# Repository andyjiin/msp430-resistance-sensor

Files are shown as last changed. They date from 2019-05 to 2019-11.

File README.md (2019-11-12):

# msp430-resistance-sensor
Resistance Sensor Embedded System built for ECE 298 by Andy Jin and Kelly Tang

### Problem Statement
Resistance can be measured a variety of different ways, but the setup is often tedious without the proper equipment and there is a lot of room for error. Design a resistance sensing device that utilizes analog voltage sensing and has notable features such as auto-ranging and user-friendly display to solve this problem 

### Design
Our design for the resistance sensor is bascially that of a simple voltage divider. Given a constant input voltage, and a known reference resistor, we can measure the voltage drop across the unknown resistance and solve for the unknown resistance. To give it the auto-ranging feature, we need a variety of reference resistors which will switch automatically based on input resistance. 

### Prototype
Shown below is the initial prototype working with a 8-to-1 mux breakout board and MSP430 discovery board.
<p align="center">
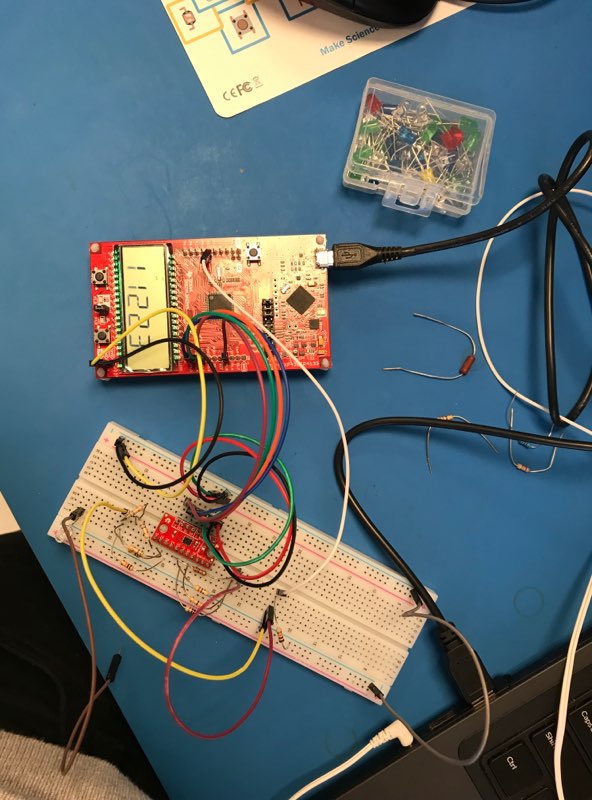
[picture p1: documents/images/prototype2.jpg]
  
</p>

### PCB
Once we finalized the design, a PCB was manufactured and we were able to stress test our product to ensure it met specifications and requirements. We can see in the image that given a 620 Ohm resistor, our output was 617 Ohm which gave us an error of < 1% which was well below our expected at ~5% (of course we have to note that the resistor itself has internal error). 
<p align="center">
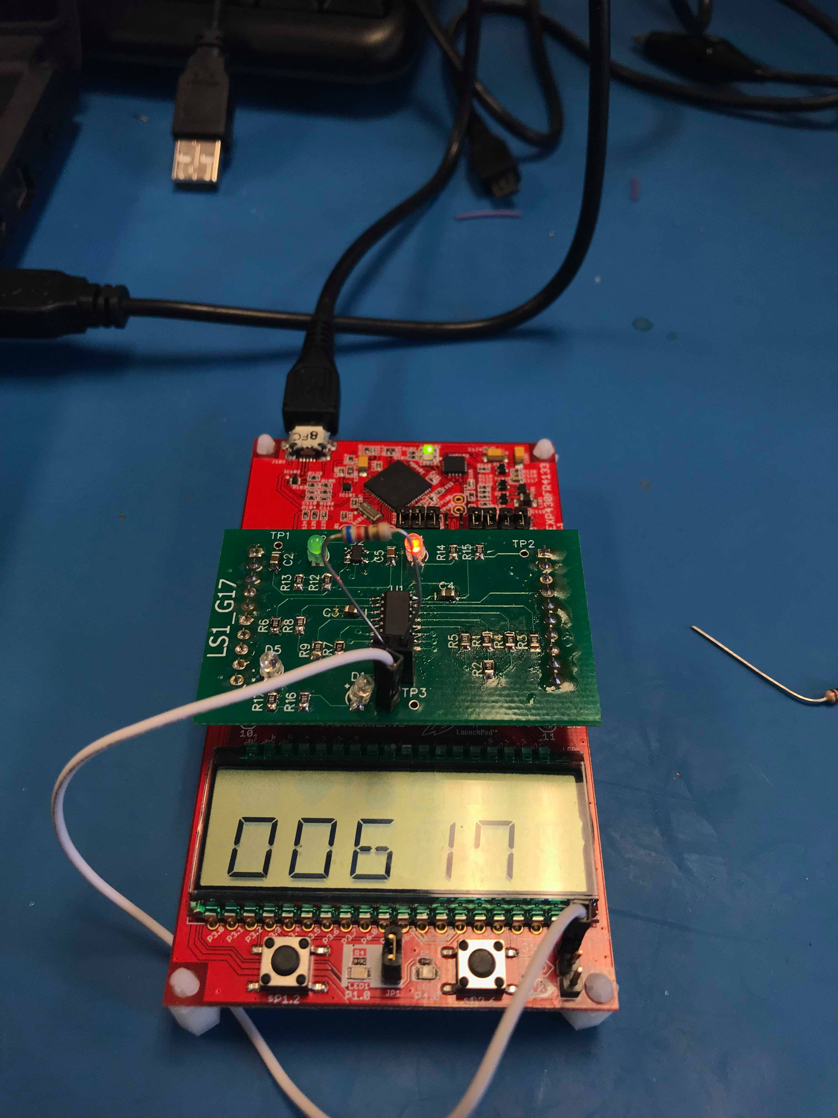
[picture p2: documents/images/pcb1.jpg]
  
</p>

### Remarks
We had some hardware issues that we would like to resolve if there were to be a rev 2. Firstly, we found our accuracy dropped considerable beyond 10 kOhm which is due to the fact that the low-impedence ADC input of the MSP430 adds another resistor in parallel with the input resistor which would skew the voltage reading across our unknown resistor. We would like to add some sort of buffer between the resistor circuit and the ADC input pin. Secondly, we had to manually short one of a pins which was misconnected (as seen in the images with the white jumper cable).

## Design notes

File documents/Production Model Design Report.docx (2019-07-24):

# Production Model Design Report

S2019

Lab Section: | 1 | Group: | 17

# Team Members

# | Name | Role

1 | Andy Jin | Software, prototyping and integration testing
2 | Kelly Tang | Schematic, layout and PCB bring-up

# Design Overview

## Problem Statement

Resistance can be measured a variety of different ways, but the setup is often tedious without the proper equipment and there is a lot of room for error. Design a resistance sensing device that utilizes analog voltage sensing and has notable features such as auto-ranging and user-friendly display to solve this problem.

## Design Scope

The project solves the problem by using a simple voltage divider in conjunction with the MSP430’s on-board ADC to measure voltage across the unknown resistance and compare the results with a known reference resistor. The reference resistor is selectable to give the device the auto-ranging functionality and the measured resistance is displayed to the user on the LCD display.

It was assumed that the device will operate in ideal weather conditions and the object to measure is of a reasonable size (i.e. it is able to fit between the resistance sensing nodes).

## Project Design Requirements

1. The system must be able to successfully determine the resistance of an unknown object within a 10% degree of precision and accuracy
2. The system must relay information in a clear and concise format to the user
3. The system must be able to automatically adjust its resistance range according to provided object
4. The latency between connecting probes to the object and the output of the information to the user must be less than 0.1s

## System-Level Design (High-Level)

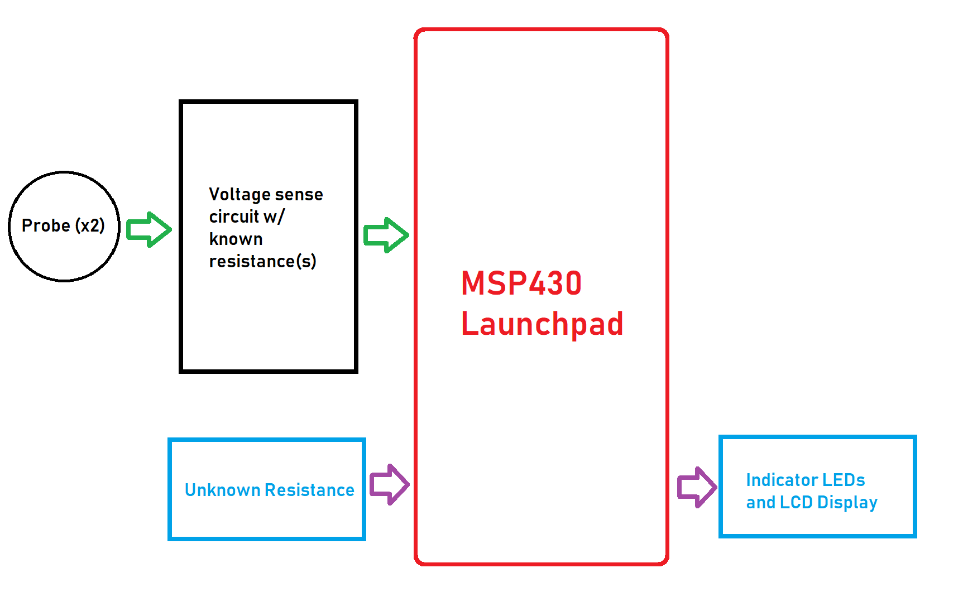
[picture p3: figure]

Figure 1: Updated Resistance Sensor High Level Block Diagram

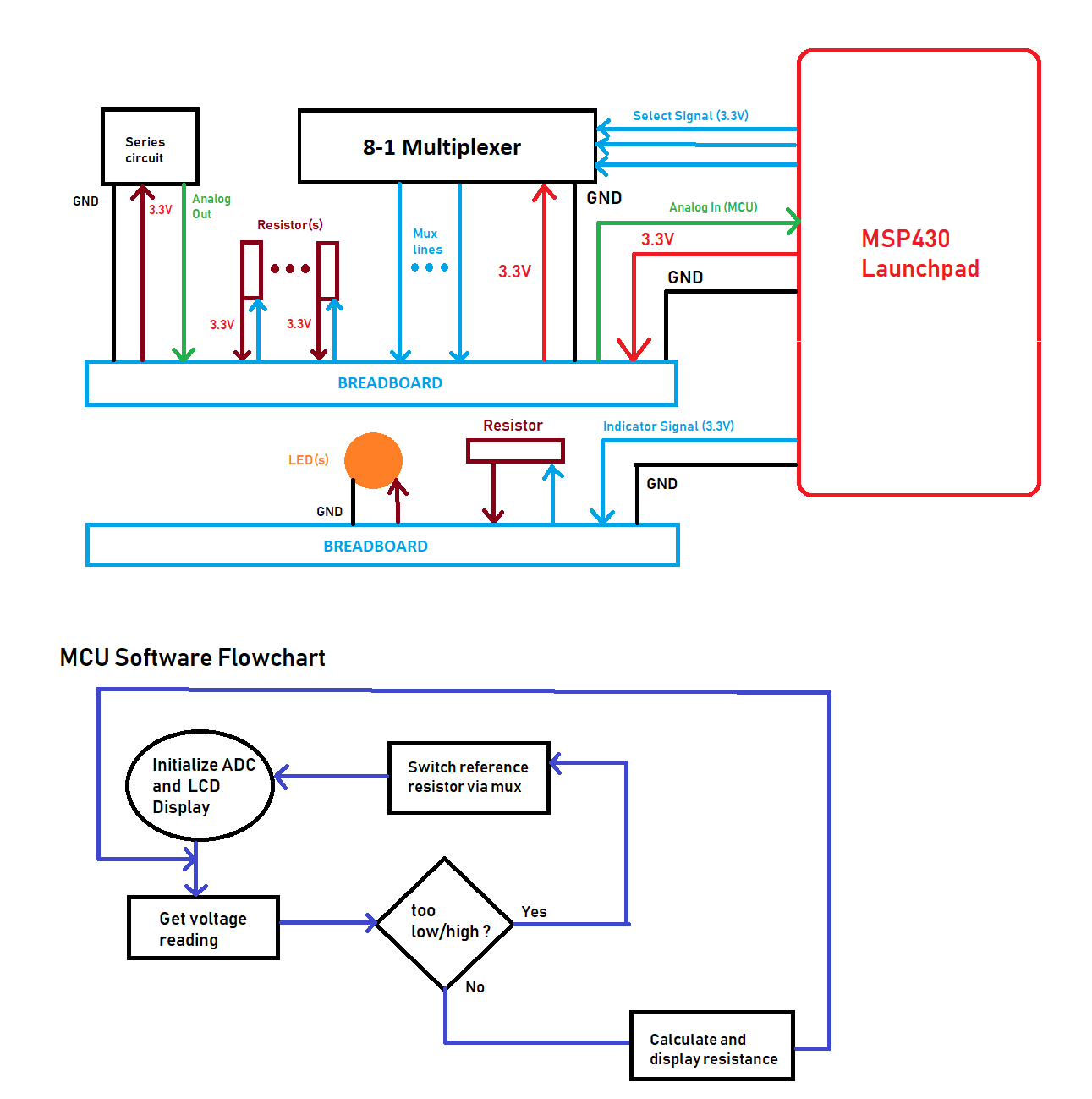
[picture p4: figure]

Figure 2: Updated Feasibility Model Design and a Software Flowchart

## Completed Prototype

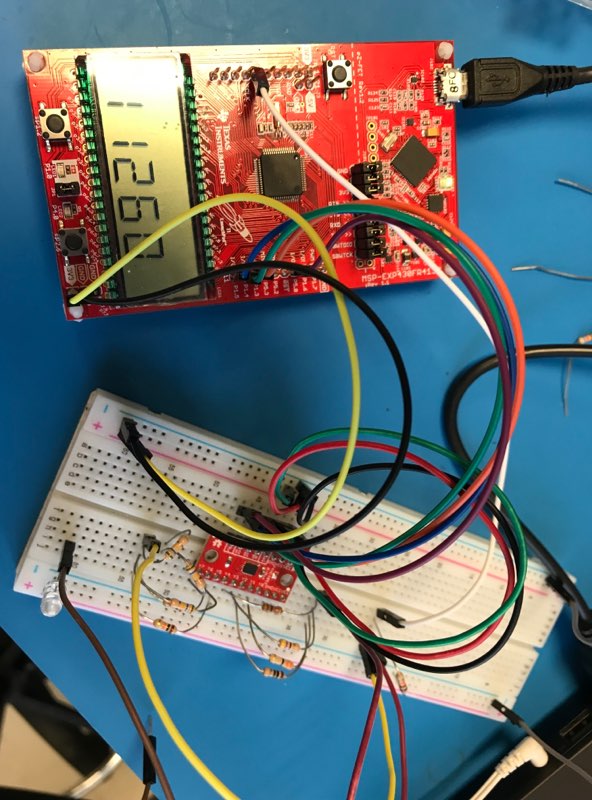
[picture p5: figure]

Figure 3 and 4: Initial Prototype for the resistance sensor utilizing the 8-to-1 mux and the LCD display

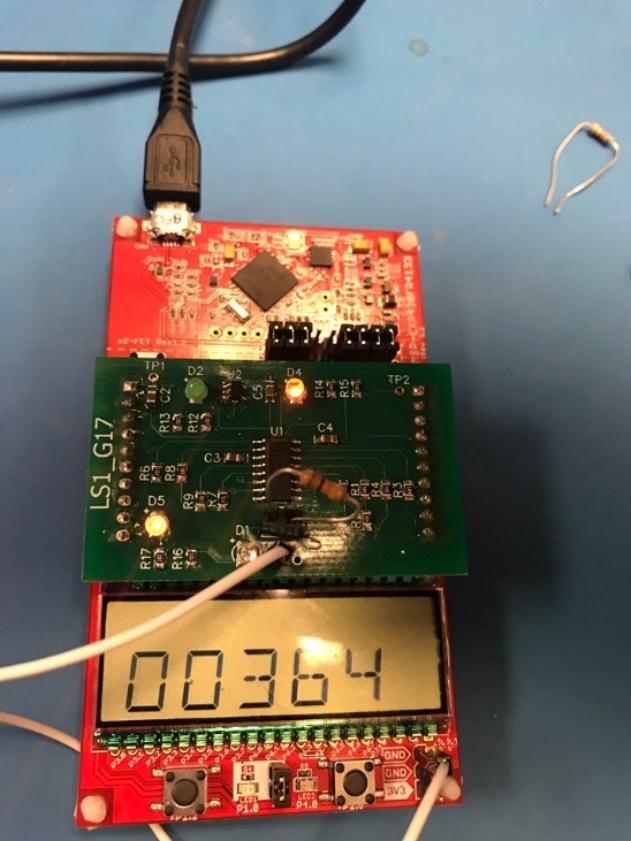
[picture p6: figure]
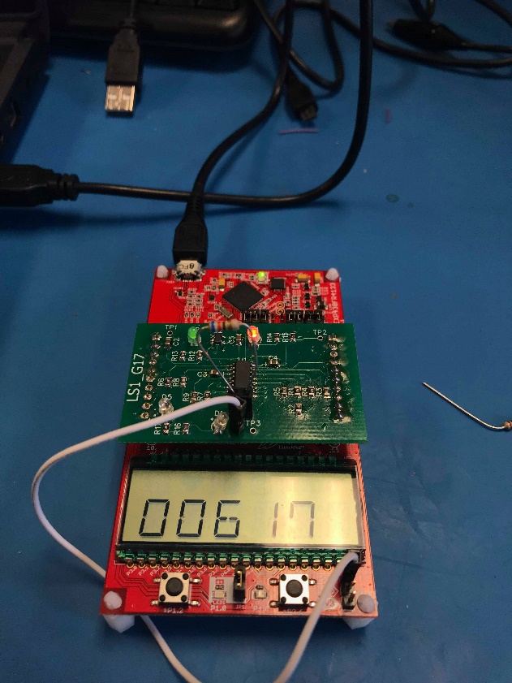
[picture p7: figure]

Figure 5 and 6: PCB displaying the resistance of the through-hole resistor with and without indicator LED

## Preliminary Production Design Changes

We had to manually short the indicator LED for the ADC connection as it interfered with the resistance calculations by adding an additional resistance. Also considering adding some form of buffer to the input of the ADC as we are seeing inaccurate values for high resistance values although the voltage drop is consistent. We are assuming this is due to the low-impedance input on the ADC pin which causes a parallel with our resistance and for high value resistances, this would greatly affect our expected voltage drop.

# Member 1 Production Details

Andy Jin – ID# 20712899

## Design for Test (DfT)

Designing for test (DfT) is a design technique in which the designer/engineer adds testability features for both hardware and software aspects of the project. Adding these testability features makes it easier to verify certain components of the project and helps with the debugging process in the case something is malfunctioning. DfT also makes it easier to design and deploy manufacturing tests and is a way of looking forward into the products lifecycle to make life easier for the engineer in the future.

In our project, we split were able to isolate our hardware into 2 major components which we could test individually and designed our software around individually testing the functionality of the hardware components. We used DfT principals when adding hardware test-points to our PCB schematic and layout in addition to adding numerous indicator LEDs to make it easier to identify what was wrong (e.g. connection issues or software issues).

It should be noted that our device runs 3V3 across the unknown resistance that it is measuring so it should be noted that the device that is placed in between the probes should be able to withstand this voltage. Additionally, it should also be noted by the production engineer that because the device is a measuring device, it is very sensitive to hardware connection issues and external environment factors such as temperature. The results of the resistance sensor will behave differently if there is a connection issue and a common one is if there is a problem with the probe connection.

## Energy Efficiency

Energy efficiency is the concept of using less electricity/energy to provide the same service. It is an important goal of many electrical products and systems as it may extend the products lifetime or lowers the cost of use of the product which ultimately results in a more desirable product. With the increased movement towards environmental friendliness, energy efficiency in products is becoming an increasingly desirable trait to consumers.

Our project is fairly energy efficient but there are numerous aspects in which we can improve upon. For one, when there is no connection (i.e. no unknown resistance between the probes) we are still outputting 3V3 which is a huge waste of energy as when the device is idle it should be in its low-power mode. Additionally, because we leave the probes floating, the value measured on the ADC is constantly fluctuating and may cause the mux to switch reference resistors many times which also wastes a lot of energy. Despite this, we are still relatively energy efficient as our voltage divider circuit is fairly simple and does not consume a lot of energy in the first place. We are also able to achieve a fair amount of accuracy with the 3V3 which means that we don’t need an external power source and the low-voltage is sufficient.

It should be noted that in regards to energy efficiency, the device should not be plugged in while not in use because we currently do not have a low-power mode implemented. Also leaving a resistor plugged in to the probes for a long period of time is also not ideal as it is constantly consuming energy. For production purposes, until the low-power mode is implemented via software, stress testing of numerous units at a time is not advised.

# Member 2 Production Details

Jiaming Tang – ID# 20716244

## Design for Manufacturability (DfM)

DFM is the process of designing a product that’s easy to manufacture and is cost-effective. DFM optimizes manufacturing functions such as fabrication, assembly, test, and procurement. If done well, DFM ensures that the product meets quality, cost, and turnaround time expectations.

To design our system using DFM, we wanted to make sure our PCB layout meets fabrication design rules, uses standard components, and is simple enough to assemble. We used trace widths of at least 0.2mm and spaced our traces apart by at least 0.3mm, to ensure that the PCB manufacturing company is able to fabricate our design without any trouble, time-delay, or extra costs. We also used standard components by only using components and modules listed in the course requirements. Those components are widely used and easily accessible. Finally, we made our PCB so that it’s easy to assemble. A board that’s too complex or crowded with components mean that it’s harder to sort through components and look at the design to figure out where to place each component.

Steps for the production engineer that will take our prototype through to a production-ready product include:

- Perform DFM analysis to identify and fix issues. DFM software can identify design issues that could have severe consequences on PCB fabrication (e.g. acid traps, insufficient annular rings, missing solder mask between pads).
- Testing the design to ensure that it complies with safety and quality standards. For example, does our board get too hot during use?
- Determining the manufacturing process, such as considering the quantity of parts being made, who will fabricate the PCBs, etc.

## RoHS

RoHS (Restriction of Hazardous Substances) restricts the use of specific materials found in electrical and electronic products due to their hazardous effects on the environment. The six restricted substances include lead, mercury, cadmium, hexavalent chromium, polybrominated biphenyls, and polybrominated diphenyl ethers. These substances are dangerous to be exposed to, both during manufacturing and disposal. The goal of RoHS is to reduce the environmental and health impacts of electronics.

This topic relates to our project because there is lead in the solder we use, which is substance restricted by the RoHS. We use the traditional lead solder since it’s widely used and requires a lower melting temperature than lead-free solder. However, if we throw away components or boards that we soldered, we’re contributing to the electronic waste that can contaminates the environment with hazardous chemicals.

Steps and considerations for the production engineer that will take our prototype through to a production-ready product include:

- Determining if our PCB design and manufacturing process is RoHS compliant. The production engineer should consider hiring a PCB manufacturer that makes lead-free PCBs, and follows RoHS requirements.
- If lead-free PCB manufacturing is selected, the engineer should compare the cost, board performance, and shelf-life of the lead-free PCB to a PCB that contains lead.
- Determine if there are ways to safely dispose of the PCB and any materials used in the manufacturing/assembly process. The engineer should check if any parts of the PCB (e.g. the copper) can be recycled, and be aware of procedures for chemical waste disposal of hazardous substances.

# References

[1] | "IEEE Style," 2019. [Online]. Available: https://pitt.libguides.com/citationhelp/ieee.

# Appendix – Detailed Design

Table 1: Necessary Design Changes

# | Change | Reason/Notes

1 | Update resistor values for multiplexer | There were some discontinuities in values we can measure with the old resistors
2 | Connect Z input within multiplexer to 3.3V | Some misunderstandings on how the multiplexer functions resulted in incorrect connection of the Z output
3 | Averaged the ADC values to reduce noise | The values of the ADC were changing too frequently due to noise

Table 2: Important Notes

# | Note

1 | The enable pin on the multiplexer is active low
2 | The resistance sensing circuit is more accurate if the reference resistor is higher than the unknown resistance
3 | The ADC internal reference voltage can be adjusted to be 3.3V or 1.5V

Table 3: Hardware Signal Test Plan

Signal (TP*) | Property | Required Software Mode | Min | Nominal | Max
Mux Enable | Voltage | Setup | 0 V | | 3.3 V
Mux Select 0 | Voltage | Switching resistances | 0 V | | 3.3 V
Mux Select 1 | Voltage | Switching resistances | 0 V | | 3.3 V
Mux Select 2 | Voltage | Switching resistances | 0 V | | 3.3 V
ADC In (*) | Voltage | Connecting new resistance | 0 V | | 3.3 V

*Indicates Test Point Required

Table 4: Hardware Signal Connectivity

Signal | MSP430FR4133 Pin | LaunchPad J1/J2 Pin | Prototype Connection
Analog In | P8.0 (A8) | J2 pin 6 | Unknown resistor
Analog Out | P5.0 | J3 pin 4 | Mux Enable
Analog Out | P1.3 | J3 pin 8 | Mux Select 0
Analog Out | P1.4 | J3 pin 9 | Mux Select 1
Analog Out | P1.5 | J3 pin 10 | Mux Select 2

Repository: https://github.com/andyjiin/msp430-resistance-sensor

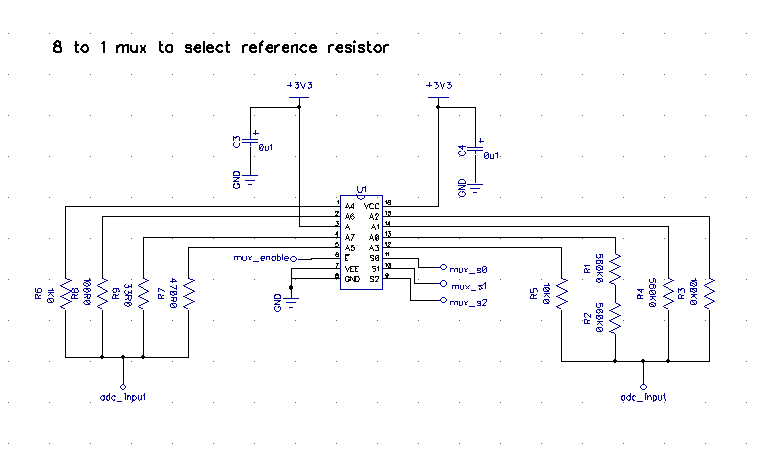
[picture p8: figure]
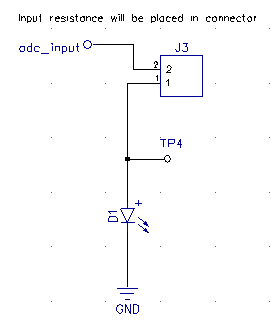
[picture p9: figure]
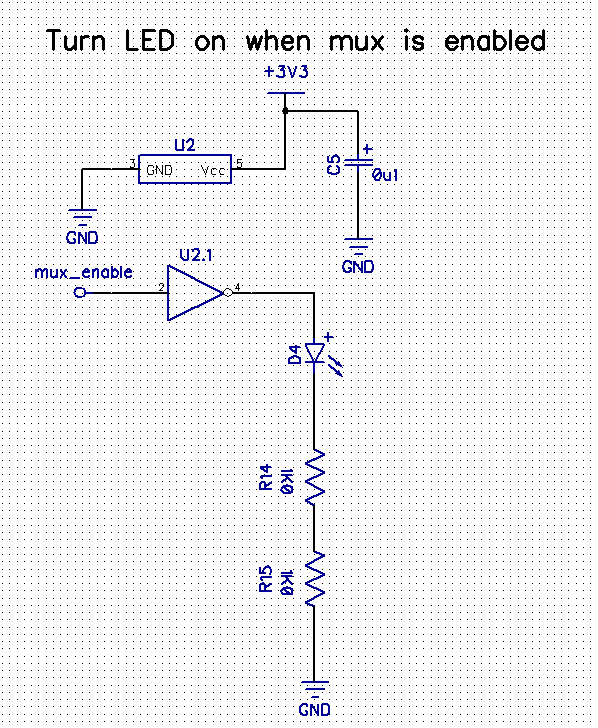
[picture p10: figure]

ECE 298 S2019 – Production Model Design Report

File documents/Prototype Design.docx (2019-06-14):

# Prototype Design

S2019 – Edit this document into a deliverable.

Lab Section: | 1 | Group: | 17

# Necessary Changes and Notes

Answer these questions by editing and adding to Table 1 and Table 2 below.

Table 1: What changes had to be made to get your Feasibility Model working as expected?

Table 1: Necessary Design Changes

# | Change | Reason/Notes

1 | Update resistor values for multiplexer | There were some discontinuities in values we can measure with the old resistors
2 | Connect Z input within multiplexer to 3.3V | Some misunderstandings on how the multiplexer functions resulted in incorrect connection of the Z output
3 | Averaged the ADC values to reduce noise | The values of the ADC were changing too frequently due to noise

Table 2: Lessons Learned – Is there anything you want to remember so that you don’t make the same mistake again? Or, not waste time on something you already figured out?

Table 2: Important Notes

# | Note

1 | The enable pin on the multiplexer is active low
2 | The resistance sensing circuit is more accurate if the reference resistor is higher than the unknown resistance
3 | The ADC internal reference voltage can be adjusted to be 3.3V or 1.5V

# Signal Specifications

Answer these questions by editing and adding to Table 3 below.

Table 3: For all the important signals in your Prototype:

- Name the signal
- State which signal property is important (voltage, frequency, rise time, etc.)
- State whether you need to include a Test Point (TP) on the PCB so you can probe the signal
- State which software mode will let you test the signal as indicated
  - You may need to create a special test mode in your code to exercise the signal to its limits
- State the Minimum (Min), Nominal, and Maximum (Max) acceptable values for that signal property
- Include signals for attached components, modules, sensors, etc. Do not include power rails.

Table 3: Hardware Signal Test Plan

Signal (TP*) | Property | Required Software Mode | Min | Nominal | Max
Mux Enable | Voltage | Setup | 0 V | | 3.3 V
Mux Select 0 | Voltage | Switching resistances | 0 V | | 3.3 V
Mux Select 1 | Voltage | Switching resistances | 0 V | | 3.3 V
Mux Select 2 | Voltage | Switching resistances | 0 V | | 3.3 V
ADC In (*) | Voltage | Connecting new resistance | 0 V | | 3.3 V

*Indicates Test Point Required

# Signal Mapping

Answer these questions by editing and adding to Table 4 below.

Table 4: How will your Prototype design electrically connect to the LaunchPad?

MSP430FR4133 IC pin <--> BoosterPack pin on J1/J2 of the LaunchPad <--> Your Prototype

Table 4: Hardware Signal Connectivity

Signal | MSP430FR4133 Pin | LaunchPad J1/J2 Pin | Prototype Connection
Analog In | P8.0 (A8) | J2 pin 6 | Unknown resistor
Analog Out | P5.0 | J3 pin 4 | Mux Enable
Analog Out | P1.3 | J3 pin 8 | Mux Select 0
Analog Out | P1.4 | J3 pin 9 | Mux Select 1
Analog Out | P1.5 | J3 pin 10 | Mux Select 2

# Tips for making your schematic

This is covered in the DipTrace Schematic Design Guidelines document but is noted here for convenience in the order it appears in Checklist #2.

- All schematic sheets have a border with Project Name, Lab Session, and Group. This makes it really clear whose schematic is whose.
- There is a common GND used for 5.0 V and 3.3 V powered devices. This ensures that 0 V is the same for all pins and devices.
- Add a GND header pin to your board so that lab equipment probes can have a signal reference. You can clip onto it with scope probe ground or alligator clips.
- There are bulk decoupling capacitors (10 µF) added for power pins. They work like charge gas tanks to keep the voltage high during a current spike.
- There are device decoupling capacitors (100 nF) added between device power and GND pins. This gives a low impedance path for noise voltage to GND instead of through the device.
- All signal nets are named and assigned to their appropriate net class. Just like variables in your code, you want to explicitly name everything in your schematic.
- Analog signals are kept separate from digital signals to avoid switching noise via capacitive coupling.
- Test points are included as per Table 3.
- The last schematic sheet is a Bill of Materials (BOM).
- An ERC (Electrical Rules Check, under Verification → Electrical Rule Check in DipTrace) for schematic net connections has been run successfully.
- The schematic is “reader friendly”
  - Busses to group signals. For example, if an IC needs eight data bits, group them in a bus
  - Don’t make the reader hunt for net connection endpoints
  - Nets are neat and tidy, aligned with each other, and not unnecessarily crisscrossing
- Expected rail currents are listed. Add up all the max current you expect to draw from 3.3 V and 5.0 V and note them in the schematic.

# Tips for making your PCB

This is covered in the DipTrace PCB Design Guidelines document but is noted here for convenience in the order it appears in Checklist #2.

- The PCB form factor has (X, Y) corner coordinates at (0.0, 0.0); (57.2, 0.0); (57.2, 34.3); and (0.0, 34.3) measured in mm. This is the required board size we need so we can get it properly fabricated.
- The Launchpad connectors are at (X, Y) = (5.7, 17.8) mm for J1; and at (X, Y) = (51.4, 17.8) mm for J2. Otherwise, your PCB won’t fit onto the LaunchPad BoosterPack headers.
- The remaining components are properly placed and grouped This means that components working together are nearby.
- The devices are properly oriented for best routing. E.g., resistors in parallel should be placed side by side oriented so that the commonly shared nets are physically close.
- The decoupling capacitors are properly placed and routed, meaning they are physically close to the device power pins
- The PCB has test points in appropriate locations (physically accessible by a scope probe, near the signal of interest).
- Silkscreen includes reference designators, identifiers, and polarity markings (include Pin 1 marking for multi-pin components – could be a dot, a number ‘1’, etc.)
- Silkscreen text and markings are of adequate size and are not on pads
- (LAB SESSION#_GROUP#) been added on the Top Silkscreen layer by the J1 connector (e.g. 2_13)
- DRC (Design Rules Check, under Verification → Check Design Rules in DipTrace) passes with the ECE-298_mm.rul file. This means that there are no anticipated fabrication problems (traces aren’t too narrow, too wide, no unrouted nets, etc.)
- LVS (Layout vs Schematic, under Verification → Compare To Schematic in DipTrace) passes design net connectivity comparison with schematic

# Other Best Practices

- Keep decoupling capacitors close to digital device power pins
- Keep adequate space around components to add part identifier silkscreen info (“R1”, “C6”, etc.)
- Separate analog devices power/GND signal paths from digital devices power/GND routes
- If there is room, add info in the Top Silkscreen layer for indicator functions (e.g., “Temp Good”, “Test Mode”, etc.)
- You may place components on the bottom if the need arises (i.e., insufficient room on the top side), but it is usually cheaper in production to get all components on one side of a PCB, if possible.
- Your circuit devices may have connections that include GND as a reference (see below). Especially for ANALOG signals it is important to route the GND connection for signals separately from GND returns for devices, otherwise power noise may be coupled from the signal to the MCU.

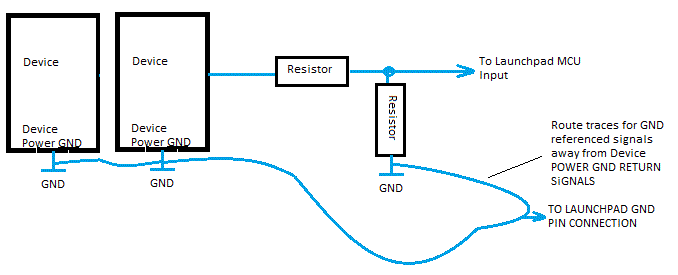
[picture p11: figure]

Prototype Design

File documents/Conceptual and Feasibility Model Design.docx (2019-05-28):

# Conceptual and Feasibility Model Design

S2019

Lab Section: | 1 | Group: | 17

# Conceptual Design (High-Level)

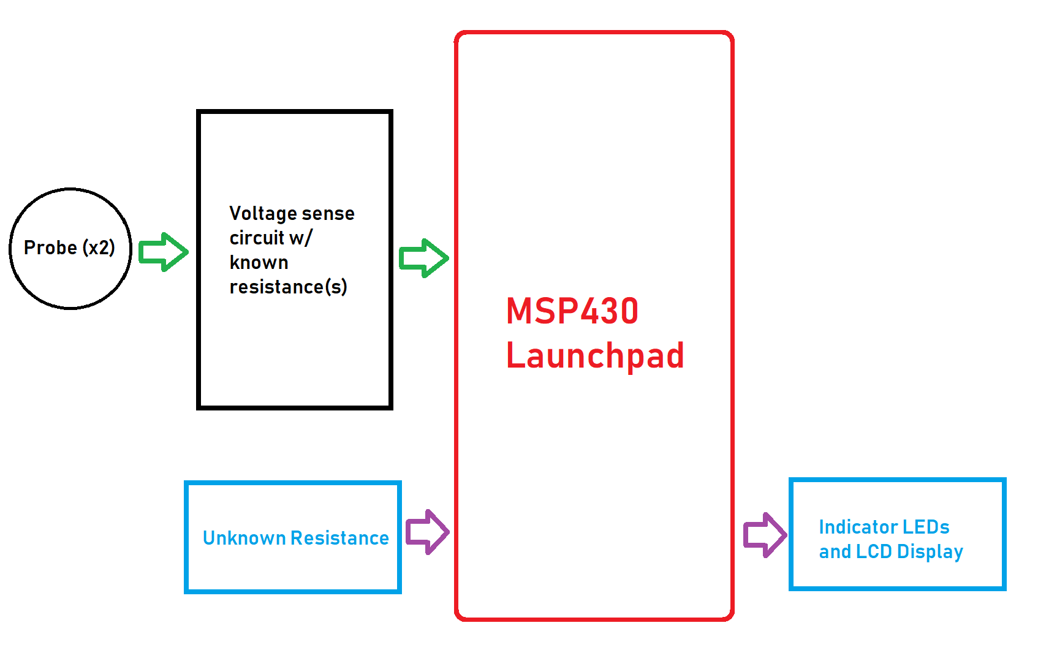
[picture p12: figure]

Figure 1: Resistance Sensor High Level Block Diagram

## Project Design Requirements

In order to measure the success of the resistance sensing project, the project must satisfy the following 4 requirements:

1. The system must be able to successfully determine the resistance of an unknown object within a certain degree of precision and accuracy
2. The system must relay information in a clear and concise format to the user
3. The system must be able to automatically adjust its resistance range according to provided object
4. The latency between connecting probes to the object and the output of the information to the user must be relatively low

## Project Sensors

The number sensors required for the resistance measuring device is low. In terms of sensors, we just need two probes that of which is similar to those found on a DMM. This is to allow our voltage sensing circuit to run through the unknown resistance and to perform the necessary calculations to determine resistance values. There “sensors” allow current flow across the unknown resistor which therefore causes a voltage drop. This voltage drop is an analog signal which can be measured via the MSP430 onboard ADC.

## Project Actuators and Indicators

In terms of actuators, there is none as the resistance sensing system is simply relaying information to the user and not controlling any external devices. There are, however, numerous indicators one of which is the LCD display which is used to output the resistance values in addition to the SI units of the unknown resistance. In addition to the LCD display, there are indicator LEDs which indicate whether a stable connection has been made (with the probes to the unknown resistance), whether the device is powered and if an error has occurred (e.g. unknown resistance outside range of system).

## Project Software Interfaces

In order to read the voltage from the resistance sensing circuit, it is necessary to use an ADC to gather and interpret data. In addition to this, GPIO functions to control indicators such as LEDs and to control the 8-to-1 mux select lines to switch between reference resistors. The majority of the information processed via software would be through the ADC and displayed via the LCD display onboard the MSP430 Launchpad. Finally, the raw values of the ADC must be averaged in a way that preserves accuracy but at the same time limits the input noise.

## Project User Interfaces

The user-input for the resistance sensing module would be an object with unknown resistance placed in between the two probes. Because the resistance sensor is auto-ranging, there should be little to no interference from the user other than possibly a reset button however the MSP430 Launchpad has an onboard reset button which may be utilized. An indicator LED would light up if a successful connection has been made and the LCD display will output the measured resistance with SI units. Any error that may have occurred would either be displayed on the LCD display or indicator LED.

## Project Testing Methodology (brief)

To validate resistance readings, we may simply verify the module against a DMM. In addition to this we may also find it useful to use variable resistances or potentiometers to demonstrate precision and accuracy of the resistance sensing module. Initially when testing the standalone ADC to measure voltage drops, we may also find it useful to verify readings against an oscilloscope. Ideally, the tester would observe little fluctuations in a static resistor and resistance readings that don’t differ too much from indicated resistance values (e.g. from DMM or colour bands).

# Project Feasibility Model Design and Software Flowchart (High-Level)

A simplified example is shown in Figure 2. Replace this figure with a high-level block diagram of your system.


Figure 2: Simple Sketch of a Feasibility Model Design and a Software Flowchart

- List what modules (including quantities) are needed from the ECE 298 Parts spreadsheet for your Feasibility Model Design
- List the internal MCU resources needed to interface to the Modules (e.g. ADC, timer, etc.)
- List the MCU GPIO pins needed to connect MCU resources (e.g. ADC, timer, etc.) to the modules

Hardware Components needed:

- MCP430 Launchpad (x1)
- 8-to-1 Multiplexer (x1)
- Red LED (x1)
- Green LED (x1)
- Yellow LED (x1)
- 100, 500, 1k, 10k, 100k, 500k, 1M resistors

In terms of internal resources, it is necessary for the resistance sense module to use ADCs and GPIOs. In addition to this, timers may be used to sample and average data from the ADC to reduce noise in the system.

MCU Pins:

- P8.1 – ADC
- P2.7 and P2.5 - GPIO

Conceptual and Feasibility Model Design

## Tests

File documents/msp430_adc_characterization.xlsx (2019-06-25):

Via MUX |  |  | Normal
ADC Raw | Voltage |  | ADC Raw | Voltage
9 | 0 |  | 10 | 0
49 | 200 |  | 60 | 200
125 | 400 |  | 114 | 400
196 | 600 |  | 190 | 600
247 | 800 |  | 253 | 800
311 | 1000 |  | 300 | 1000
366 | 1200 |  | 370 | 1200
441 | 1400 |  | 434 | 1400
499 | 1600 |  | 500 | 1600
546 | 1800 |  | 555 | 1800
607 | 2000 |  | 623 | 2000
684 | 2200 |  | 684 | 2200
732 | 2400 |  | 740 | 2400
802 | 2600 |  | 812 | 2600
869 | 2800 |  | 875 | 2800
938 | 3000 |  | 943 | 3000
1003 | 3200 |  | 1008 | 3200
Resistor | Min Range | Max Range
33 | 1.03125 | 33
100 | 3.125 | 100
470 | 14.6875 | 470
1000 | 31.25 | 1000
10000 | 312.5 | 10000
100000 | 3125 | 100000
560000 | 17500 | 560000
1120000 | 35000 | 1120000
Resistor | Min Range | Max Range
33 | 3.3 | 21.45 | 1 < x < 20
100 | 10 | 65 | 21 < x < 60
470 | 47 | 305.5 | 61 < x < 300
1000 | 100 | 650 | 301 < x < 600
10000 | 1000 | 6500 | 601 < x < 6000
100000 | 10000 | 65000 | 6001 < x < 60000
560000 | 56000 | 364000 | 60001 < x < 300000
1120000 | 112000 | 728000 | 3000001 < x < 1120000

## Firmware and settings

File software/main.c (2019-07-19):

#include <limits.h>
#include <stddef.h>
#include <msp430.h>
#include "driverlib.h"
#include "Board.h"

#include "lcd_display.h"
#include "adc.h"
#include "mux.h"
#include "resistance.h"
#include "indicator.h"

#define SYSTEM_DELAY 100000

void main (void) {
    WDT_A_hold(WDT_A_BASE);

     // Initialize modules
     adc_init();
     lcd_display_init();
     mux_init();
     indicator_init();

     // Select reference resistor to begin characterization
     mux_ref_resistor ref_resistor = MUX_REF_RESISTOR_33_OHM;
     mux_select(ref_resistor);

     bool auto_range = false;
     indicator_set(true);

     while(1) {
         // Read the voltage from the ADC and calculate the resistance
         uint16_t voltage = adc_read();
         uint32_t resistance = RESISTANCE_CALCULATE(voltage, mux_convert_resistance(ref_resistor));

         // Perform adjustments on the calculated resistance (auto-ranging)
         // If the resistance is within range of the reference resistor
         if (resistance > 0 && resistance < MUX_REF_RESISTOR_33_OHM_UPPER_BOUND) {
             if (ref_resistor != MUX_REF_RESISTOR_33_OHM) { // If we need to update the reference resistor
                 ref_resistor = MUX_REF_RESISTOR_33_OHM;
                 auto_range = true;
                 indicator_set(false);
             }
         } else if (resistance >= MUX_REF_RESISTOR_33_OHM_UPPER_BOUND && resistance < MUX_REF_RESISTOR_100_OHM_UPPER_BOUND) {
             if (ref_resistor != MUX_REF_RESISTOR_100_OHM) { // If we need to update the reference resistor
                  ref_resistor = MUX_REF_RESISTOR_100_OHM;
                  auto_range = true;
                  indicator_set(false);
              }
         } else if (resistance >= MUX_REF_RESISTOR_100_OHM_UPPER_BOUND && resistance < MUX_REF_RESISTOR_470_OHM_UPPER_BOUND) {
             if (ref_resistor != MUX_REF_RESISTOR_470_OHM) { // If we need to update the reference resistor
                  ref_resistor = MUX_REF_RESISTOR_470_OHM;
                  auto_range = true;
                  indicator_set(false);
              }
         } else if (resistance >= MUX_REF_RESISTOR_470_OHM_UPPER_BOUND && resistance < MUX_REF_RESISTOR_1_KOHM_UPPER_BOUND) {
             if (ref_resistor != MUX_REF_RESISTOR_1_KOHM) { // If we need to update the reference resistor
                  ref_resistor = MUX_REF_RESISTOR_1_KOHM;
                  auto_range = true;
                  indicator_set(false);
              }
         } else if (resistance >= MUX_REF_RESISTOR_1_KOHM_UPPER_BOUND && resistance < MUX_REF_RESISTOR_10_KOHM_UPPER_BOUND) {
             if (ref_resistor != MUX_REF_RESISTOR_10_KOHM) { // If we need to update the reference resistor
                  ref_resistor = MUX_REF_RESISTOR_10_KOHM;
                  auto_range = true;
                  indicator_set(false);
              }
         } else if (resistance >= MUX_REF_RESISTOR_10_KOHM_UPPER_BOUND && resistance < MUX_REF_RESISTOR_100_KOHM_UPPER_BOUND) {
             if (ref_resistor != MUX_REF_RESISTOR_100_KOHM) { // If we need to update the reference resistor
                  ref_resistor = MUX_REF_RESISTOR_100_KOHM;
                  auto_range = true;
                  indicator_set(false);
              }
         } else if (resistance >= MUX_REF_RESISTOR_100_KOHM_UPPER_BOUND && resistance < MUX_REF_RESISTOR_560_KOHM_UPPER_BOUND) {
             if (ref_resistor != MUX_REF_RESISTOR_560_KOHM) { // If we need to update the reference resistor
                  ref_resistor = MUX_REF_RESISTOR_560_KOHM;
                  auto_range = true;
                  indicator_set(false);
              }
         } else if (resistance >= MUX_REF_RESISTOR_560_KOHM_UPPER_BOUND && resistance < MUX_REF_RESISTOR_1120_KOHM_UPPER_BOUND) {
             if (ref_resistor != MUX_REF_RESISTOR_1120_KOHM) { // If we need to update the reference resistor
                  ref_resistor = MUX_REF_RESISTOR_1120_KOHM;
                  auto_range = true;
                  indicator_set(false);
              }
         } else {
             // If we have reached here, it means that the resistance calculated may not be reliable as it is not within
             // the acceptable range of this module
             indicator_set(true);
         }

         // If the auto-range flag is set, we must update the reference resistor correspondingly
         if (auto_range) {
             auto_range = false;
             mux_select(ref_resistor);
         }

         // TODO: Handle units via the LCD
         if (resistance > USHRT_MAX) {
             resistance = resistance/1000;
             indicator_set(true);
         } else {
             indicator_set(false);
         }

         lcd_display_show_on_screen(resistance, NULL); // Call display function to show the numbers on the screen
         __delay_cycles(SYSTEM_DELAY); // System delay
     }
}

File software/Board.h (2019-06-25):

/* --COPYRIGHT--,BSD
 * Copyright (c) 2017, Texas Instruments Incorporated
 * All rights reserved.
 *
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
 * *  Redistributions of source code must retain the above copyright
 *    notice, this list of conditions and the following disclaimer.
 *
 * *  Redistributions in binary form must reproduce the above copyright
 *    notice, this list of conditions and the following disclaimer in the
 *    documentation and/or other materials provided with the distribution.
 *
 * *  Neither the name of Texas Instruments Incorporated nor the names of
 *    its contributors may be used to endorse or promote products derived
 *    from this software without specific prior written permission.
 *
 * THIS SOFTWARE IS PROVIDED BY THE COPYRIGHT HOLDERS AND CONTRIBUTORS "AS IS"
 * AND ANY EXPRESS OR IMPLIED WARRANTIES, INCLUDING, BUT NOT LIMITED TO,
 * THE IMPLIED WARRANTIES OF MERCHANTABILITY AND FITNESS FOR A PARTICULAR
 * PURPOSE ARE DISCLAIMED. IN NO EVENT SHALL THE COPYRIGHT OWNER OR
 * CONTRIBUTORS BE LIABLE FOR ANY DIRECT, INDIRECT, INCIDENTAL, SPECIAL,
 * EXEMPLARY, OR CONSEQUENTIAL DAMAGES (INCLUDING, BUT NOT LIMITED TO,
 * PROCUREMENT OF SUBSTITUTE GOODS OR SERVICES; LOSS OF USE, DATA, OR PROFITS;
 * OR BUSINESS INTERRUPTION) HOWEVER CAUSED AND ON ANY THEORY OF LIABILITY,
 * WHETHER IN CONTRACT, STRICT LIABILITY, OR TORT (INCLUDING NEGLIGENCE OR
 * OTHERWISE) ARISING IN ANY WAY OUT OF THE USE OF THIS SOFTWARE,
 * EVEN IF ADVISED OF THE POSSIBILITY OF SUCH DAMAGE.
 * --/COPYRIGHT--*/
/**
 * ===
 * Board.h
 * ===
 * This file is meant to provide generic GPIO selection definitions that allows
 * DriverLib to be used portably across different LaunchPads. The same module
 * pin might not be populated on the same physical port and pin on different
 * LaunchPads.
 *
 * This file is intended to be modified and updated by individual users based
 * on application need. It will be initially populated according to common
 * peripherals available on a LaunchPad board, but by all means not complete.
 *
 * GPIO_PRIMARY_MODULE_FUNCTION indicates Port SEL bits are 01
 * GPIO_SECONDARY_MODULE_FUNCTION indicates Port SEL bits are 10
 * GPIO_TERNARY_MODULE_FUNCTION indicates Port SEL bits are 11
 * If the Port SEL bits are 00, the FUNCTION bits should be ignored
 * Please consult device datasheet for more info, under "Input/Output Diagrams"
 *
 **/

#ifndef __BOARD_H__
#define __BOARD_H__

#ifdef __MSP430FR4133__

#define GPIO_PORT_LED1          GPIO_PORT_P1
#define GPIO_PIN_LED1           GPIO_PIN0
#define GPIO_PORT_LED2          GPIO_PORT_P4
#define GPIO_PIN_LED2           GPIO_PIN0
#define GPIO_PORT_S1            GPIO_PORT_P1
#define GPIO_PIN_S1             GPIO_PIN2
#define GPIO_PORT_ADC8          GPIO_PORT_P8
#define GPIO_PIN_ADC8           GPIO_PIN0
#define GPIO_FUNCTION_ADC8      GPIO_PRIMARY_MODULE_FUNCTION
#define GPIO_PORT_MCLK          GPIO_PORT_P1
#define GPIO_PIN_MCLK           GPIO_PIN4
#define GPIO_FUNCTION_MCLK      GPIO_PRIMARY_MODULE_FUNCTION
#define GPIO_PORT_SMCLK         GPIO_PORT_P8
#define GPIO_PIN_SMCLK          GPIO_PIN0
#define GPIO_FUNCTION_SMCLK     GPIO_PRIMARY_MODULE_FUNCTION
#define GPIO_PORT_ACLK          GPIO_PORT_P8
#define GPIO_PIN_ACLK           GPIO_PIN1
#define GPIO_FUNCTION_ACLK      GPIO_PRIMARY_MODULE_FUNCTION

#define GPIO_PORT_UCA0TXD       GPIO_PORT_P1
#define GPIO_PIN_UCA0TXD        GPIO_PIN0
#define GPIO_FUNCTION_UCA0TXD   GPIO_PRIMARY_MODULE_FUNCTION
#define GPIO_PORT_UCA0RXD       GPIO_PORT_P1
#define GPIO_PIN_UCA0RXD        GPIO_PIN1
#define GPIO_FUNCTION_UCA0RXD   GPIO_PRIMARY_MODULE_FUNCTION

#define GPIO_PORT_UCB0SCL       GPIO_PORT_P5
#define GPIO_PIN_UCB0SCL        GPIO_PIN3
#define GPIO_FUNCTION_UCB0SCL   GPIO_PRIMARY_MODULE_FUNCTION
#define GPIO_PORT_UCB0SDA       GPIO_PORT_P5
#define GPIO_PIN_UCB0SDA        GPIO_PIN2
#define GPIO_FUNCTION_UCB0SDA   GPIO_PRIMARY_MODULE_FUNCTION

#define GPIO_PORT_MUX_SELECT0   GPIO_PORT_P1
#define GPIO_PIN_MUX_SELECT0    GPIO_PIN3
#define GPIO_PORT_MUX_SELECT1   GPIO_PORT_P1
#define GPIO_PIN_MUX_SELECT1    GPIO_PIN4
#define GPIO_PORT_MUX_SELECT2   GPIO_PORT_P1
#define GPIO_PIN_MUX_SELECT2    GPIO_PIN5

#define GPIO_PORT_MUX_ENABLE    GPIO_PORT_P5
#define GPIO_PIN_MUX_ENABLE     GPIO_PIN0

#define GPIO_PORT_INDICATOR    GPIO_PORT_P8
#define GPIO_PIN_INDICATOR     GPIO_PIN2

#endif // __MSP430FR4133__

#endif // __BOARD_H__

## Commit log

2019-06-01 Working ADC module and initial code for mux (#4)
    - Cleaned up ADC so it's 100% functional now
    - Mux still needs work but heres the initial code
2019-06-14 Add prototype design document (#6)
    [msp430_adc_characterization.xlsx]
2019-06-17 Added schematic rev1, updated folder names (#7)
2019-06-25 Implement auto-ranging functionality (#9)
    * Initial implementation of auto-ranging
    * Add linker command script
    [msp430_adc_characterization.xlsx]
2019-06-25 Updated resistance conversions and add indicator LED (#10)
    * Updated resistance conversions after testing
    * Added indicator LED functionality
2019-06-27 Added pcb layout, gerber files, updated schematic (#12)
2019-06-29 Gerber files (#13)
    * added pcb layout, gerber files, updated schematic
    * unzipped gerber files
    [BoardOutline.gko, Bottom.gbr, BottomMask.gbr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]
2019-07-19 Pin Remapping for Demo (#15)
2019-07-19 Cleanup code after demo (#16)
    * Pin Remapping for Demo
    * Clean up code after demo
